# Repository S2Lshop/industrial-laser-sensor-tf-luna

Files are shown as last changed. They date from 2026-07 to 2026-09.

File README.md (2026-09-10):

# Industrial Laser Distance Sensor (RS485/0–20 mA/4-20mA)
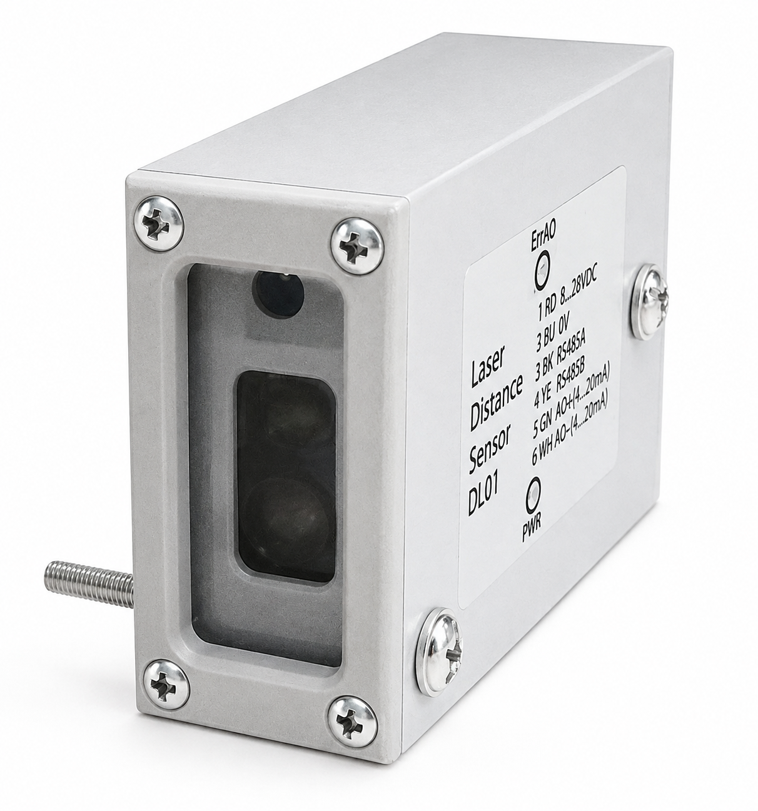
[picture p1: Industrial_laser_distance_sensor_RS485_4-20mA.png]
Industrial Laser Distance Sensor

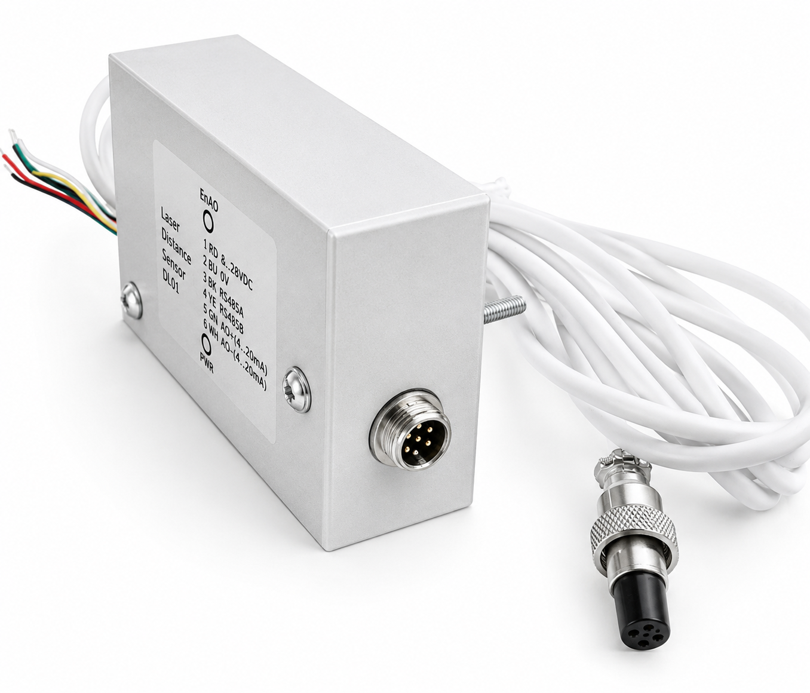
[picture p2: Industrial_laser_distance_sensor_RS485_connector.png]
Industrial laser distance sensor RS485 connector

Industrial laser distance sensor with a protected aluminum enclosure, simultaneous RS485 Modbus RTU and active 0–20 mA/4–20 mA interfaces. Suitable for industrial automation, process control, level monitoring, agriculture, and many other real-world applications.

## Features
- Simultaneous RS485 Modbus RTU and active 0–20 mA/ 4–20 mA outputs
- Configurable for level monitoring, empty/full tank detection, and alarm applications
- Adjustable alarm thresholds and hysteresis
- Two-point distance calibration
- Analog output calibration
- Adjustable measurement scaling
- Configurable digital filtering
- TF-Luna ToF laser module
- EEPROM parameter storage
- User-upgradable firmware via RS-485
  
## Specifications
- Measurement range: 0.2–8 m*
- Resolution: 1 mm
- Update rate: 1–100 Hz (configurable via Modbus registers)
- Supply voltage: 8–28 VDC
- Power consumption: ≤ 3 W
  
The sensor is currently operating on a concrete block production line for automatic concrete mixture dosing.

## Videos

### Automatic Dosing (Close View)
https://youtube.com/shorts/zwSHPJO99uA

### Automatic Dosing (Front View)
https://youtube.com/shorts/gGjYULFCIdY

### Operator HMI Display
Measurements from both laser sensors (K1 and K2)
https://youtu.be/ycKj416GfGs

## More Information

Hackaday Project:
https://hackaday.io/project/206284-custom-industrial-laser-distance-sensor

The sensor is available for purchase on [SmallRun](https://smallrun.net/shop/s2lstudio/industrial-laser-distance-sensor-rs485-4-20ma).
<a href="https://smallrun.net/shop/s2lstudio" target="_blank" rel="noopener">
  
</a>

## License

Free for personal use and hobby projects.
Credit is appreciated — tag @S2Lshop if you build something with these files!

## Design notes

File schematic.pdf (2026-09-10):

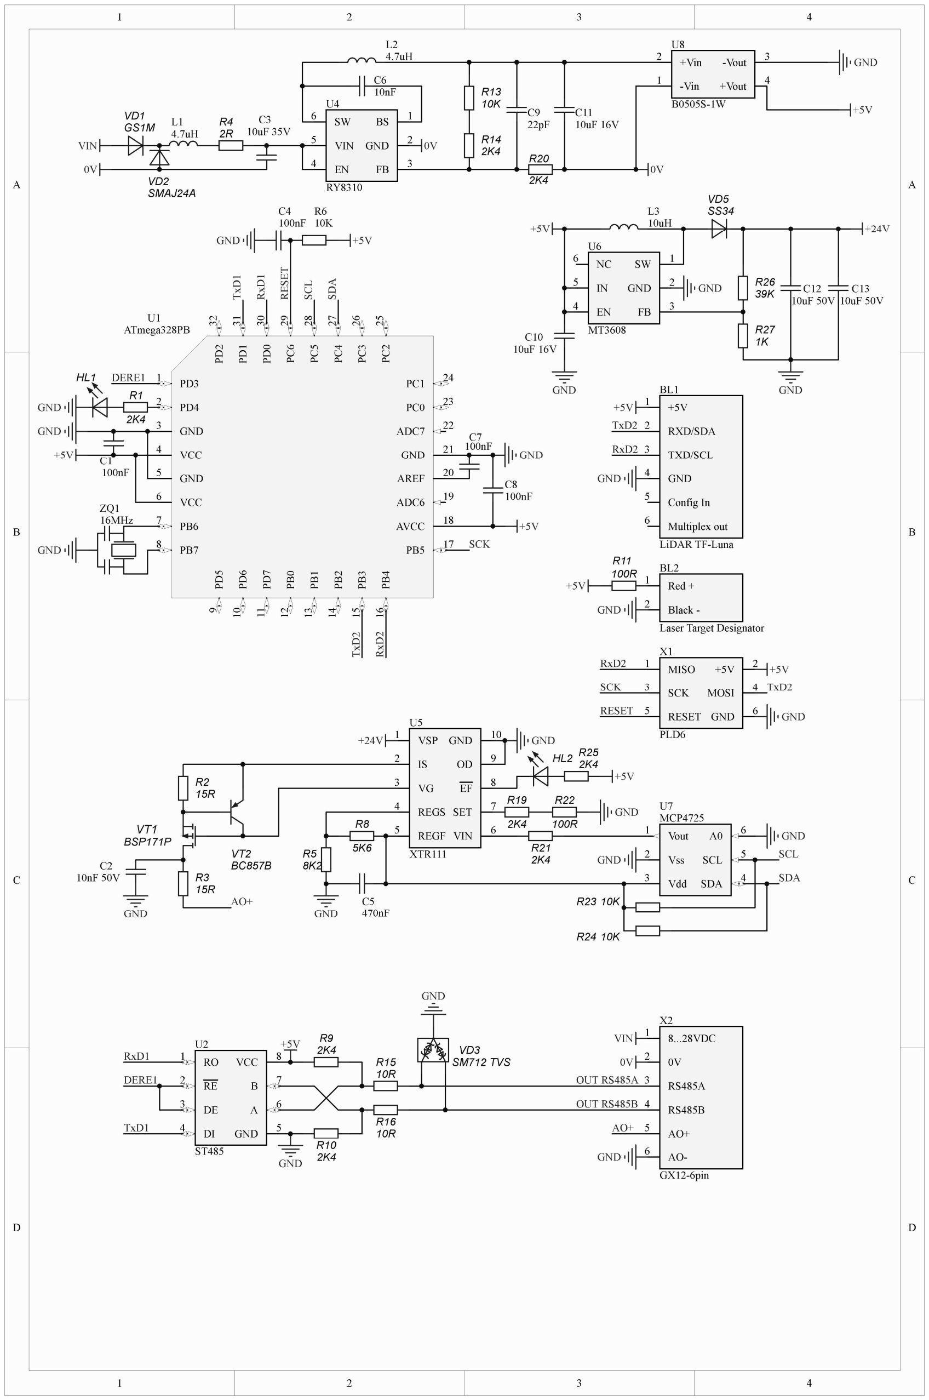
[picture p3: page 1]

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
RxD2

TxD2

RO 1

RE 2

DE 3

DI 4

VCC | 8
B | 7
A | 6
GND | 5

U2

ST485

RxD1

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
OUT RS485B

OUT RS485A

GND

TxD1

DERE1

VSP 1

IS 2

VG 3

REGS 4

| GND | 10
| OD | 9
| EF | 8
| SET | 7
REGF 5 | VIN | 6

U5

XTR111

Vout 1

Vss 2

Vdd 3

A0 | 6
SCL | 5
SDA | 4

U7
MCP4725

C4
100nF TxD¹ RxD¹

PD3 1

PD4 2

GND 3

VCC 4

GND 5

VCC 6

PB6 7

PB7 8 | PD⁵

### 9 PD6 10 PD7 11 PB0 12 PB1 13 PB2 14 PB3 15 PB4 16

PC1 | 24
PC0 | 23
ADC7 | 22
GND | 21
AREF | 20
ADC6 | 19
AVCC | 18
PB5 | 17 PD² ³² | PD¹ ³¹ | PD⁰ ³⁰ | PC⁶ ²⁹ | PC⁵ ²⁸ | PC⁴ ²⁷ | PC³ ²⁶ | PC² ²⁵U1
ATmega328PB

+5V

+5V

GND

GND

C7
100nF
C1
100nF
C8

100nF RESET

RESET

SCK

SCK | SCK 3

MISO 1

RESET 5

+5V | 2
MOSI | 4
GND | 6

X1

PLD6

+5V

GND

R6
10K

VD1
GS1M
R14
2K4
BS | 1
GND | 2
FB | 3

SW 6

VIN 5

EN 4

U4

RY8310

C6
10nF

L2
4.7uH

R20

2K4

R13
10K
C3
10uF 35V

C11
10uF 16V

C9
R4 | 22pF
2R

L1
4.7uH

VD2
SMAJ24A

VIN

+5V

DERE1 | TxD² | RxD²

SCL

SDA SCL SDA

GND

GND

R8

5K6 R5
8K2

GND

R23 10K

R24 10K

GND

R21
2K4

C5
470nF

R19

2K4

R22

100R

GND

GND | +5V

+24V
HL2 R25
2K4
+5V

VT2
BC857B

VT1
BSP171P

R2
15R

R3
15R

GND

C2
10nF 50V

GND

-Vin 1

+Vin 2

-Vout | 3
+Vout | 4

U8

B0505S-1W

0V | 0V

0V

SW | 1
GND | 2
FB | 3

NC 6

IN 5

EN 4

U6

MT3608

L3
10uH

GND

+5V

C12
10uF 50V

VD5
SS34
+24V

GND

C13
10uF 50V

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
16MHz

GND

RxD2

TxD2

C10
10uF 16V

HL1
R1

2K4

GND

AO+

AO+

VD3
SM712 TVS

GND

RXD/SDA 2

+5V 1

TXD/SCL 3

GND 4

Config In 5

Multiplex out 6

BL1

LiDAR TF-Luna

Black - 2

Red + 1

BL2

Laser Target Designator

GND

R11
100R
+5V

0V 2

8...28VDC 1

RS485A 3

RS485B 4

AO+ 5

AO- 6

X2

GX12-6pin

+5V

GND

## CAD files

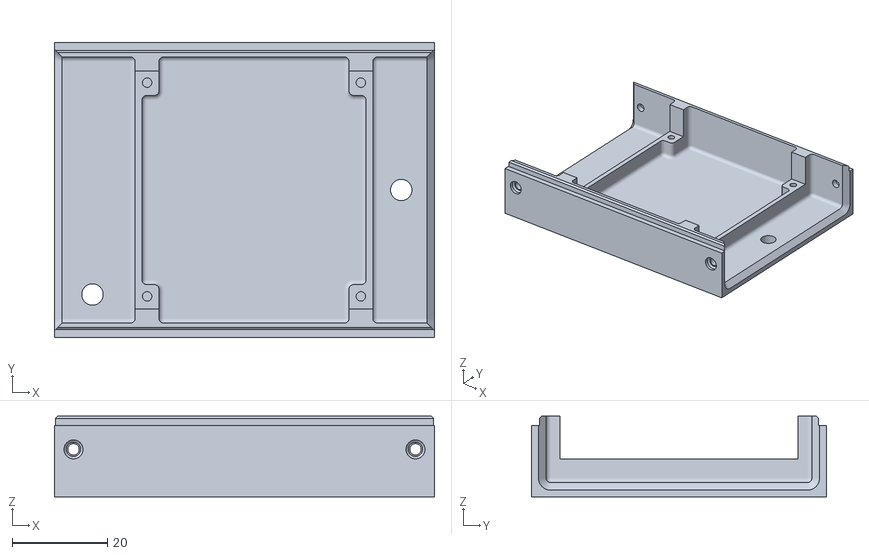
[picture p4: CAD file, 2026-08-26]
enclosure_stl/DL_bottom_enclosure.STL
80.0 x 62.0 x 17.0

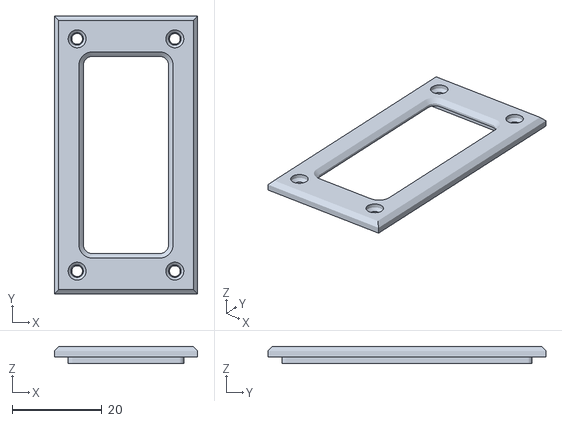
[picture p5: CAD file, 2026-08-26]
enclosure_stl/DL_front_cover_trim.STL
32.0 x 62.0 x 3.80

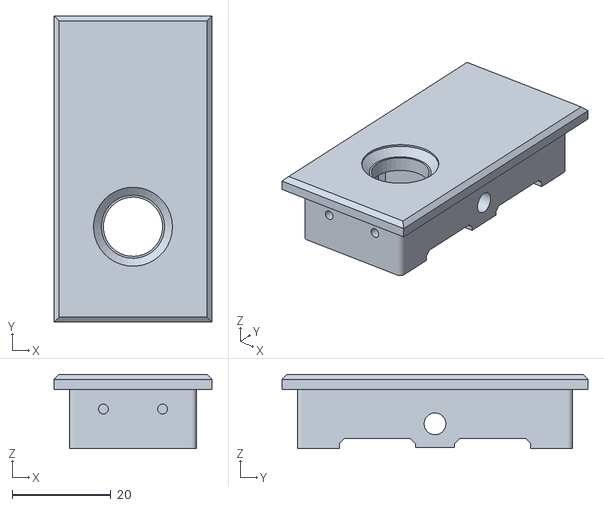
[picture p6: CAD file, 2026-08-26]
enclosure_stl/DL_back_cover.STL
32.0 x 62.0 x 15.0

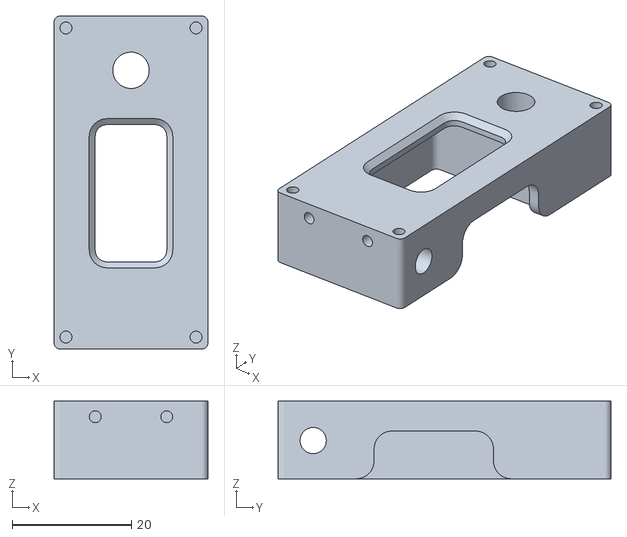
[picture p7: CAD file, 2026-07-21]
enclosure_stl/DL_front_cover.STL
25.8 x 55.8 x 13.0

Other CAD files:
enclosure_stl/DL_top_enclosure.STL

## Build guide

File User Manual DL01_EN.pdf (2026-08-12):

# User Manual: Industrial Laser Distance Sensor (RS485/ Modbus/0-20 and 4-20 mA)

### Chapter 1. General Information and Principle of Operation

### 1.1 Device Purpose

The industrial laser distance sensor is designed for continuous non-contact measurement of the distance to the surface of a monitored object, automatic calculation of the current fill level of bins, bunkers, reservoirs, or silos (in percent), and timely detection of emergency overfill thresholds.

Measurement data and alarm statuses are transmitted simultaneously via a digital industrial RS-485 interface (Modbus RTU protocol) and are formed as a continuous signal on the analog output (active current loop). Depending on the settings, the device supports two industrial standards of analog output: 4–20 mA (traditional standard with wire-break monitoring) and 0–20 mA (full-scale standard).

The device is designed for use within automated process control systems (PCS), environmental monitoring complexes, and dispatch systems of industrial and warehouse facilities.

### 1.2 Time of Flight (ToF) Measurement Principle

The optical measurement module is based on the Time of Flight (ToF) method. The sensor periodically emits modulated light pulses in the near-infrared range (850 nm wavelength) and receives the signal reflected from the object. The computing core determines the time delay (phase shift) between the emitted and received waves, which is used to calculate the exact distance to the object.

The received physical distance data is fed into the built-in microcontroller, where it undergoes two-stage digital filtering:

Moving median cascade: Effectively cuts off random impulse noise and spikes caused by dust in the working area or strong structural vibrations.
Exponential moving average (EMA) smoothing: Stabilizes and smooths the readings, preventing phase jitter while maintaining a high response speed of the system to physical level changes.

Then the filtered distance is scaled according to the calibration coefficients, recalculated into the container fill level (0–100%), and matched with the discrete alarm setpoints.

1.

2.

DL01 • User Manual | Page 1 of 15

### 1.3 Main Technical Parameters of the Device

Operating measurement range: from 0.2 to 8.0 meters (hardware blind zone on receiver — 200 mm). Measurement error (accuracy):
±6 centimeters in the range of 0.2 to 3 meters;
±2% of the measured value in the range of 3 to 8 meters.

Measurement resolution (discreteness): 1 mm (due to interpolation in the built-in filter). Sensor polling frequency: configurable, from 1 to 100 Hz.
Supply voltage: 8…28 V direct current (VDC). Recommended operating nominal value is 12 V. Power consumption: not more than 3 W.
Communication interface: RS-485, half-duplex (9600 bps, 8N1).
Analog output: active 4–20 mA / 0-20 mA (12-bit DAC resolution, load resistance of the loop — not more than 250 Ohm).
Non-volatile memory: EEPROM (write endurance of at least 100,000 cycles).

### Chapter 2. Installation Requirements and ToF Measurement Physics

To ensure stable and trouble-free operation of the laser rangefinder, the physical principles of ToF measurements of the semiconductor emitter must be strictly taken into account.

2.1 "Blind Zone" (Ranging Blind Zone)

The hardware blind zone of the sensor is 200 mm (20 cm) from the front cover glass. Any objects closer than this distance cannot be correctly processed by the optical ToF receiver due to the photodiode saturation
effect. If an object is closer than 200 mm, the sensor returns a value of | 0 mm | . Programmatic or calibration
elimination of the blind zone is not possible. The device must be mounted so that the maximum material fill level never comes closer than 220–250 mm to the sensor face (including a technological margin).

### 2.2 Target Reflectivity (Reflectivity) and Maximum Range

The maximum measurement range of the sensor directly depends on the diffuse reflection coefficient of the material's surface:

Light/white surfaces (90% reflection coefficient): the maximum detection range is 8.0 meters. Dark/black surfaces (10% reflection coefficient): the maximum range is reduced to 2.5 meters due to infrared absorption by the material.

When monitoring the level of coal, coke, or wet dark soil, the effective measurement range narrows to 2.5 m. For monitoring the level of light-colored cement, lime, dry sand, or light plastic granules, the sensor operates stably at distances up to 8 m.

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
### 2.3 Field of View (FoV) and Light Spot Diameter

The laser beam of the emitter diverges in a cone with a full Field of View (Field of View, FoV) of 2° (half angle β = 1°). The measurement will be stable and accurate only if the light spot completely falls on the reflective surface of the measured material. The minimum required diameter of a flat target area d at a distance D is calculated by the formula:

### d = 2 × D × tan(1°) ≈ 0.035 × D

Light spot diameter vs distance table:

Distance to material (D), m | Minimum working spot diameter (d), cm
1,0 | 3.5
2,0 | 7.0
3,0 | 10.5
4,0 | 14.0
5,0 | 17.5
6,0 | 21.0
7,0 | 24.5
8,0 | 28.0

If the light spot partially hits two objects at different distances (e.g., the edge of the spot touches protruding rebar, a ladder, or the bin wall), the sensor will output an abnormal average distance with a high margin of error. The beam must be directed strictly perpendicular to the monitored plane and pass far from internal structures.

### 2.4 Influence of Ambient Light (Ambient Light Immunity)

The optical circuit of the sensor has built-in protection against ambient light up to 70 Klux. Direct sunlight hitting the receiver lens can paralyze the receiver tract or drastically reduce accuracy. For outdoor mounting or installation in semi-open bins, the sensor must be protected by an opaque hood (visor). Directing the sensor at powerful artificial sources of infrared radiation (such as halogen floodlights) is not allowed.

### 2.5 Complex Surface Types and Obstacles in the Working Zone

Specular surfaces: Highly reflective glossy surfaces (mirrors, polished metal, completely calm clean water) reflect the laser beam directionally away, leading it away from the sensor's receiver. To monitor the level of such media, the beam must be directed strictly at an angle of 90° to the plane, or a diffuse reflection target float must be placed on the specular surface.
Transparent media: Ordinary glass, transparent acrylic, or water let the infrared beam pass through them. Mounting the sensor behind glass inspection windows is strictly prohibited.
Dustiness: A dense suspension of dust at the moment of loading bulk material weakens the useful signal (the signal amplitude Reg 1 drops sharply). In such conditions, it is necessary to use the maximum EMA damping level ( Reg 13 from 40% to 80%) to maintain stable readings during technological loading cycles.

### Chapter 3. Electrical Connection

### 3.1 Cable and Power Requirements

The electrical installation of the device is performed using a round shielded cable (recommended type — KSPVE or shielded twisted pair). The cable shield is grounded on one side (on the control cabinet side) to minimize electromagnetic interference on the RS-485 line and the DAC. The supply voltage must be from 8 to 28 VDC. A power supply of 12 VDC is recommended as the operating source — this ensures an optimal thermal regime and leaves a power reserve on the supply bus for connecting other modules (such as a separate laser transmitter / "head" board). The internal sensor controller is hardware-protected against reverse polarity, but exceeding the supply voltage above 30 V will lead to irreversible failure of the device.

### 3.2 Connector Pinout and Color Marking

The connection is made through a sealed instrument connector. Below is the pinout layout on the soldering/ cable connection side (view from pin side):

Table of Conductors Assignment:

Contact Number | Wire Color | Signal Name | Assignment
1 | Red | VCC | Power supply plus (+8…28 VDC, recom. 12 VDC)
2 | Blue | GND | Power supply minus / Common

•

•

•

3
4 2

5 1

6

Contact Number | Wire Color | Signal Name | Assignment
3 | Black | RS485-A | Direct line of the RS-485 half-duplex interface
4 | Yellow | RS485-B | Inverse line of the RS-485 half-duplex interface
5 | Green | AO+ | Positive terminal of the active current loop (output current)
6 | White | AO- | Negative terminal of the active current loop (common ground)

### 3.3 Connection of the RS-485 Interface Line and the Analog Output

RS-485 Line: At the ends of long network segments (over 150 meters), terminating resistors with a nominal value of 120 Ohm (0.25 W) must be installed between wires A and B. The network topology must strictly correspond to the 'bus' standard. Connection of the analog output is performed according to the active scheme to passive PLC shunts (total resistance of the line is not more than 250 Ohm).

### Chapter 4. Modbus RTU Interface and Register Map

### 4.1 Protocol Parameters

Data exchange is carried out according to the Modbus RTU standard at a baud rate of 9600 bps, frame 8N1. The device acts as a Slave. Reading Holding Registers ( 03h ) and Writing ( 06h , 10h ) functions are supported.

### 4.2 Device Configuration

To configure (set up) the operating parameters of the sensor, calibrate its measurement tract, and fine-tune the analog output, you must use a personal computer or laptop running specialized software — for example, utilities from the Modbus Tools package (in particular, the Modbus Poll program) or any other terminal software supporting reading and writing registers using the Modbus RTU protocol.

The hardware connection of the device to the computer is performed via a USB ↔ RS-485 interface converter. The sensor exchanges data in real time, allowing any modified settings to be immediately applied and saved in the non-volatile EEPROM memory.

### 4.3 Detailed Register Map (Holding Registers)

Register Address | Parameter Name | Data Type | Access | Value Range | Parameter Description and Default Settings
0 | Distance | UInt16 | R | 0… 12000 | Measured and filtered distance to the object (mm).

Register Address | Parameter Name | Data Type | Access | Value Range | Parameter Description and Default Settings
1 | Sensor Signal | UInt16 | R | 0… 65535 | Amplitude of the reflected IR signal. Less than 100 — signal is weak.
2 | Sensor Temperature | Int16 | R | -40… 125 | Temperature inside the sensor enclosure (°C).
3 | Analog Output Current | UInt16 | R | 0…2000 | Current current loop value in hundredths of a mA (e.g., 1254 = 12.54 mA).
4 | Fill Level | UInt16 | R | 0…100 | Current container fill volume in percent (%).
5 | Discrete Status | UInt16 | R | 0 / 1 | Fill status: 0 — normal, 1 — threshold exceeded (overfill).
6 | System Error Status | UInt16 | R | 0…3 | Mask of active hardware device errors. Detailed in section 4.4.
7…9 | Reserved Registers | UInt16 | R | 0 | Used to align addresses of block reading. Return 0.
10 | Modbus Network Address | UInt16 | R/W | 1…247 | Device address on the network. Changes are applied immediately. Default: 1
11 | Sensor Polling Frequency | UInt16 | R/W | 1…100 | Frequency of trigger measurement pulses generation (Hz). Default: 10
12 | Median Filter Window | UInt16 | R/W | 1…15 | Sample size for the moving median. 1 — filter is off. Default: 10
13 | EMA Damping | UInt16 | R/W | 0…100 | Smoothing coefficient in %. 0 — filter is off. Default: 20 (coeff. 0.8)
14 | Calibration Point D1 | UInt16 | R/W | 0… 12000 | Physical distance reference for the first point (mm). Default: 500
15 | Calibration Point D2 | UInt16 | R/W | 0… 12000 | Physical distance reference for the second point (mm). Default: 5000
16 | Range Boundary X1 | UInt16 | R/W | 0… 12000 | Distance (mm) corresponding to the minimum current. Default: 250

Register Address | Parameter Name | Data Type | Access | Value Range | Parameter Description and Default Settings
17 | Range Boundary X2 | UInt16 | R/W | 0… 12000 | Distance (mm) corresponding to the maximum current. Default: 5000
18 | DAC Code Y1 | UInt16 | R/W | 0…4095 | 12-bit DAC code for fine-tuning the 4.00 mA current. Default: 819
19 | DAC Code Y2 | UInt16 | R/W | 0…4095 | 12-bit DAC code for fine-tuning the 20.00 mA current. Default: 4095
20 | Mode Control | UInt16 | R/W | 0…6 | Service register for calibrations and tests. See section 4.5. Default: 0
21 | Empty Bin Bottom D_empty | UInt16 | R/W | 0… 12000 | Distance to the bottom of the completely emptied container (mm). Default: 5000
22 | Full Bin Top D_full | UInt16 | R/W | 0… 12000 | Distance to the 100% fill level (mm). Default: 500
23 | DAC Output Mode | UInt16 | R/W | 0…4 | Analog output mode: `0`-Distance 4-20mA, `1`-Level 4-20mA, `2`-Distance 0-20mA, `3`-Level 0-20mA, `4`-Alarm.
24 | «Full» Threshold | UInt16 | R/W | 10…100 | Discrete status switching threshold in percent (%). Default: 90
25 | Alarm Hysteresis | UInt16 | R/W | 1…50 | Deadband zone for resetting the status in percent (%). Default: 5
26 | Analog Output Current (log. 0) | UInt16 | R/W | 0…20 | Physical current value in milliamperes (mA) for the state "Normal/Empty". Default: 0
27 | Analog Output Current (log. 1) | UInt16 | R/W | 0…20 | Physical current value in milliamperes (mA) for the state "Filled". Default: 20
28 | Startup Current on Boot | UInt16 | R/W | 0…20 | Physical current value in milliamperes (mA) on device startup. Default: 0

### 4.3 Operation of the System Error Register (Reg 6)

Register | Reg 6 | is a bit mask of the current hardware status of the device. Reading this register by the upper
level (PLC/SCADA) allows timely detection of an emergency situation on the object.

0 (0x00) — System is healthy. The ToF sensor transmits valid packets, the DAC successfully acknowledges transactions on the I²C bus.
Bit 0 (0x01) — Rangefinder Communication Error. This flag is set by the built-in software watchdog timer. If within three polling periods (3 * triggerInterval) no correct data packet is received from the measurement module, the system sets this bit. Once the data stream is restored, the error is automatically cleared.
Bit 1 (0x02) — DAC Communication Error. This flag is set if the microcontroller receives a NACK (No Acknowledge) signal from the DAC microchip when trying to write a new voltage value, or if the transaction was abnormally terminated by the hardware TWI timeout (3 ms).
3 (0x03) — Multiple Failure. Simultaneous failure of the optical module and the analog tract.

### 4.4 Description of the Mode Control Service Register (Reg 20)

Register | Reg 20 | is designed to manage commissioning processes. Writing specific codes activates service
scenarios:
0 | — Normal Mode. The analog output is controlled according to the selected mode | Reg 23 | .
1 | — Current Minimum Test. The DAC forces the output voltage corresponding to code | Reg 18 | (Y1).
The output current must be equal to 4.00 mA.
2 | — Current Maximum Test. The DAC forces the output voltage based on code | Reg 19 | (Y2). The
output current must be equal to 20.00 mA.
3 — Capture Point M1. The system reads the current distance and saves it to the EEPROM as the raw value of the first calibration point (M1).
4 — Capture Point M2 and Calculation. The system reads the current distance as the raw value of the second point (M2), calculates the calibration coefficients of the sensor, and automatically returns
Reg 20 | to | 0 | .
5 | — Empty Bin Calibration. The current filtered distance is captured and written to register | Reg 21
(D_empty). | Reg 20 | is reset to | 0 | .
6 | — Full Bin Calibration. The current distance is captured and written to register | Reg 22 | (D_full). | Reg
20 | is reset to | 0 | .

### Chapter 5. Device Calibration Procedure

### 5.1 Two-Point Sensor Calibration (D1/D2)

Calibration allows compensating for systematic error (zero offset and slope of the characteristic) caused by material reflective properties and the features of the device installation.

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
+----------------------------------------------+ | TWO-POINT SENSOR CALIBRATION (Reg 14-15) |
+----------------------------------------------+ |
v
+----------------------------------------------+
| | Set reflector to reference D1 (mm) | |
| | Write to Reg 14 = D1 | |
+----------------------------------------------+
| v
+----------------------------------------------+
| | Write to Reg 20 = 3 | |
| | (Capture raw readings M1) | |
+----------------------------------------------+
| v
+----------------------------------------------+
| | Set reflector to reference D2 (mm) | |
| | Write to Reg 15 = D2 | |
+----------------------------------------------+
| v
+----------------------------------------------+
| | Write to Reg 20 = 4 | |
| | (Capture M2, calculate & write) | |
+----------------------------------------------+

Place a flat reflector in front of the sensor at a precisely measured distance (e.g., 500 mm). Write this
value to | Reg 14 | ( | Reg 14 = 500 | ).
Send the first point capture command: write the value | 3 | to | Reg 20 | .
Move the reflector to the second precisely measured distance (e.g., 4000 mm). Write it to | Reg 15 | ( | Reg
15 = 4000 | ).
Send the second point capture and calculation command: write the value | 4 | to | Reg 20 | .
The microcontroller will automatically calculate the scaling factor and offset, write them to the EEPROM,
and return | Reg 20 | to | 0 | . Calibration is complete.

Important Note:
If the two-point calibration process is interrupted or not completed (for example, only the measurement of the first point M1 was performed using command 3, but the final command 4 was not sent for the second point M2), the device will ignore the intermediate changes. New calibration coefficients will not be calculated or saved in the non-volatile memory of the microcontroller, and the sensor will continue to use the previous valid settings.

1.

2.
3.

4.
5.

### 5.2 Container Calibration (Empty/Full Bin)

The procedure defines the physical boundaries of the tank to calculate the fill level in percent.

Step 1. Empty Bin Calibration: Completely empty the container of material. Ensure that the laser beam
falls on the bottom of the bin and does not hit foreign objects. Write the value | 5 | to | Reg 20 | . The device
will automatically save the current distance in | Reg 21 | (D_empty) and switch to the operating mode.
Step 2. Full Bin Calibration: Fill the container with material to the maximum allowable technological level.
Write the value | 6 | to | Reg 20 | . The sensor will measure the distance to the surface, save it to | Reg 22
(D_full), and return to the operating mode.

### 5.3 Built-in Protection Mechanism Against Invalid Parameters

The device's microcontroller continuously checks the parameters written by the user for physical and mathematical compatibility:

Analog Output Range Protection: The | DistMin | ( | Reg 16 | ) parameter must be strictly less than
DistMax | ( | Reg 17 | ). The program maintains a minimum difference between them of at least 10 mm.
When trying to write | X1 >= X2 | , the dependent parameter is automatically shifted by 10 mm forward or
backward, preventing division by zero in the scaling function.
Bin Range Protection: The physical distance to the bottom of the empty bin | D_empty | ( | Reg 21 | ) must
be strictly greater than the distance to the full bin | D_full | ( | Reg 22 | ). A minimum difference of 10 mm
is maintained.
Protection During Auto-capture (Modes 5 and 6): If during the empty bin measurement the operator
mistakenly writes a value when the material level is high (so that | D_empty | is less than the current
D_full | ), the program automatically shifts the | D_full | value down, preserving the 10 mm delta and
correcting the data in the EEPROM and Modbus registers. This ensures that the denominator in the level calculation formula never becomes zero and the system does not freeze.

•

•

•

•

•

### Chapter 6. Analog Output Configuration and Calibration

### 6.1 Configuring the Analog Output Current Loop

To compensate for the tolerance of the resistors in the voltage-to-current converter circuit, perform the following steps:

Connect a milliammeter in series into the analog output circuit of the sensor (contacts | AO+ | and | AO- | ).
Configuring the 4.00 mA point:
Write the value | 1 | to | Reg 20 | . The output will be forced into the minimum current generation mode.
Modify the internal raw DAC code in register | Reg 18 | (Y1) up or down until the milliammeter reading
is exactly 4.00 mA.
Write | 0 | to | Reg 20 | to save the calibration code Y1 in the EEPROM.

Configuring the 20.00 mA point:
Write the value | 2 | to | Reg 20 | . The output will switch to the maximum current generation mode.
Modify the register | Reg 19 | (Y2) until the milliammeter reading is exactly 20.00 mA.
Write | 0 | to | Reg 20 | to save the calibration code Y2 in the EEPROM.

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
### 6.2 Description of Analog Output Operating Modes (Reg 23)

The data source for forming the current signal is selected via register | Reg 23 | :

0 — 'Distance 4-20 mA' Mode (default) (corresponds to 4.2 amps). The output current is linearly scaled
according to the distance between points | DistMin | ( | Reg 16 | ) and | DistMax | ( | Reg 17 | ).
If the distance narrows to `DistMin`, the current is 4 mA (4.00 mA).
If the distance increases to `DistMax`, the current is 20 mA (20.00 mA).

1 — 'Level 4-20 mA' Mode (corresponds to 4.2 amps). The output current is proportional to the container fill level in percent (0…100%).
At a fill level of 0% (distance is equal to or greater than `D_empty`), the current is 4 mA (4.00 mA).
At a fill level of 100% (distance is equal to or less than `D_full`), the current is 20 mA (20.00 mA).

2 — 'Distance 0-20 mA' Mode (corresponds to 0.2 amps) (NEW!). The output current is linearly scaled
according to the distance between points | DistMin | ( | Reg 16 | ) and | DistMax | ( | Reg 17 | ).
If the distance narrows to `DistMin`, the current is 0 mA (0.00 mA).
If the distance increases to `DistMax`, the current is 20 mA (20.00 mA).

3 — 'Level 0-20 mA' Mode (corresponds to 0.2 amps) (NEW!). The output current is proportional to the container fill level in percent (0…100%).
At a fill level of 0%, the current is 0 mA (0.00 mA).
At a fill level of 100%, the current is 20 mA (20.00 mA).

4 — 'Alarm' Mode (discrete). The current output operates in discrete mode:
If | Reg 5 | (fill status) is `0` (normal), the analog output generates the physical current specified in | Reg
26 | (default 0 mA).
If | Reg 5 | is `1` (filled), the analog output generates the physical current specified in | Reg 27 | (default
20 mA).
In this mode, the calculation mathematics and Modbus `Reg 3` work directly without inverse conversions and roundings, transmitting exact physical settings.

### 6.3 Intelligent Startup Current Management for the Analog Output (Reg 28)

Register | Reg 28 | specifies the physical current level in milliamperes [0...20] that the analog output must
deliver immediately after power is applied to the device. The program automatically synchronizes this value with the built-in EEPROM of the DAC microchip:

When writing a new startup current, the device recalculates the physical milliamperes into an internal raw DAC code, reads the current hardware configuration from the internal memory of the DAC, and performs a rewrite only if there is a mismatch. This protects the DAC EEPROM cells from premature wear.
Rewriting also occurs automatically when the | Y1 | and | Y2 | calibrations are changed, which guarantees
accurate holding of the startup current regardless of any shifts in the analog scale.

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
### 6.4 Connecting the Analog Output to Discrete Inputs (Arduino, Relay)

In alarm mode (Mode 4 of the analog output), the device operates as a threshold discrete switch. However, since the physical output is a current generator (active current loop), to connect it to standard logic inputs of microcontrollers (e.g., Arduino) or control inputs of relay modules, a current-to-voltage conversion must be performed using a shunt resistor (Rshunt).

Conversion Principle:
The current flowing through the shunt resistor creates a voltage drop across it in accordance with Ohm's law:

Uout = I · Rshunt

This voltage is fed to the digital input of the controller or relay module.

Calculation Formulas:

Calculation of the required current of the analog output (I) in milliamperes (mA) depending on the operating voltage of the input (Uctrl) and the shunt resistance (Rshunt):

### I (mA) = (Uctrl / Rshunt) · 1000

Calculation of the resistance of the shunt resistor (Rshunt) in Ohms for target currents and voltages:

### Rshunt (Ohm) = (Uctrl · 1000) / I (mA)

Where:
- Uctrl — required control voltage (logic level of triggering, e.g., 5 V or 3.3 V).
- I — specified current of the analog output in mA (configured in registers Reg 26 and Reg 27 ).
- Rshunt — resistance of the shunt resistor in Ohms (Ohm).

Table of Typical Configurations:

Input Logic Type | Required Uctrl, V | Set Current I, mA | Recommended Shunt Rshunt, Ohm | Values in Registers 26 and 27
Arduino / TTL Relay (5 V) | 5 V | 20 mA | 250 Ohm | Reg 26 = 0 mA, Reg 27 = 20 mA
ESP32 / STM32 (3.3 V) | 3.3 V | 20 mA | 165 Ohm (or 150 Ohm at I = 22 mA) | Reg 26 = 0 mA, Reg 27 = 20 mA

Resistor Power Dissipation Calculation:
To avoid overheating of the shunt resistor, its power rating must be selected taking into account the generated heat:

1.

2.

### P = I²

- Rshunt

For a current of 20 mA (0.02 A) and a 250 Ohm resistor, the power dissipation will be: P = 0.0004 · 250 = 0.1 W. It is recommended to use a standard resistor with a power rating of at least 0.125 W or 0.25 W.

### Chapter 7. Diagnostics, Troubleshooting, and Factory Reset

### 7.1 Error Codes in Register 6 and Their Interpretation

When integrating the sensor into a SCADA system, it is recommended to configure continuous monitoring of the error register `Reg 6`:

Code `1` (Rangefinder Error): Indicates no data from the laser rangefinder. Possible causes include damage to the sensor's internal ribbon cable, lack of internal power, or the sensor lenses being covered with a thick layer of dirt.
Code `2` (Analog Output Error): Indicates a fault on the I²C bus. Possible causes include a physical break in the tracks to the DAC microchip, short-circuit of the SDA/SCL lines, lack of pull-up resistors, or failure of the DAC microchip due to a voltage spike in the current loop.

### 7.2 Typical Faults Table

Fault | Possible Cause | Remedy
No Modbus communication | 1. No sensor power. 2. Swapped RS-485 A and B lines. 3. Device network address mismatch. | 1. Verify with a multimeter the presence of 8...28 V voltage on contacts 1 and 2. 2. Swap wires on contacts 3 and 4. 3. Try polling address 1 or perform a network scan.
Distance readings are frozen at 0 mm | The sensor is in the blind zone (closer than 200 mm from the target). | Move the sensor further from the material surface, respecting the minimum working distance.
Distance fluctuates erratically | 1. The material surface is unstable. 2. Foreign objects are inside the beam cone (2° FoV). | 1. Increase the median window size (`Reg 12` to 12-15) and EMA damping (`Reg 13` to 30-50%). 2. Re-mount the sensor further from walls or ladders.
Fill level is always 0% | Container empty and full calibration was not performed, or the D_empty and D_full parameters are equal (or D_empty ≤ D_full). | Perform calibration according to Chapter 5. Ensure that the empty container distance is strictly greater than the full container distance.

•

•

Fault | Possible Cause | Remedy
Current output delivers a fixed current (e.g., 4 or 20 mA) | The sensor remained in the service test mode. | Write the value 0 to the control register Reg 20 .

### 7.3 Factory Reset Procedure (Factory Reset)

To restore the device parameters to the factory default values, write the following values to the Holding registers:

Reg 10 (Network Address): 1
Reg 11 (Polling Frequency): 10 Hz Reg 12 (Median Window): 10 samples Reg 13 (EMA Damping): 20 %
Reg 14 (Calibration Point D1): 500 mm Reg 15 (Calibration Point D2): 5000 mm Reg 16 (Point X1 for DAC): 250 mm
Reg 17 (Point X2 for DAC): 5000 mm
Reg 18 (DAC Code Y1): 819 (corresponds to ~1 V) Reg 19 (DAC Code Y2): 4095 (corresponds to ~5 V) Reg 21 (Empty Container D_empty): 5000 mm
Reg 22 (Full Container D_full): 500 mm
Reg 23 (Analog Output Mode): 0 (distance mode 4-20 mA) Reg 24 (Threshold «Full»): 90 %
Reg 25 (Hysteresis): 5 %
Reg 26 (Current log. 0): 0 mA Reg 27 (Current log. 1): 20 mA
Reg 28 (Startup Current): 0 mA

Note: After writing these values, it is recommended to reboot the device's power to completely clear the RAM and initialize the filtering cascades.

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
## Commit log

2026-08-12 Rename Industrial laser distance sensor RS485 connector.png to Industrial_laser_distance_sensor_RS485_connector.png
2026-08-12 Rename Industrial laser distance sensor RS485 4-20mA.png to Industrial_laser_distance sensor_RS485 4-20mA.png
2026-08-12 Rename Industrial_laser_distance sensor_RS485 4-20mA.png to Industrial_laser_distance_sensor_RS485 4-20mA.png
2026-08-12 Rename Industrial_laser_distance_sensor_RS485 4-20mA.png to Industrial_laser_distance_sensor_RS485_4-20mA.png
